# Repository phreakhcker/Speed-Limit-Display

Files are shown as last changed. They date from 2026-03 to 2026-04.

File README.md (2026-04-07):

# Speed Limit Display

A real-time speed limit display built with an ESP32, GPS module, and OLED screen. Shows the current road's speed limit with color-coded overspeed warnings (green/yellow/red).

Uses the TomTom Snap-to-Roads API for accurate road matching — sends your heading and speed so it picks the correct road, even near highway ramps and parallel roads.

## Hardware

| Component | Details |
|---|---|
| Microcontroller | ESP32 Mini (any variant: original, S2, S3, C3) |
| GPS Module | Any NMEA-compatible (NEO-6M, NEO-7M, BN-220, etc.) |
| Display | SSD1351 128x128 SPI OLED |
| Button | One momentary pushbutton |
| Power | USB or 5V supply |

## Wiring

| ESP32 Pin | Connects To |
|---|---|
| GPIO 20 | GPS TX |
| GPIO 21 | GPS RX |
| GPIO 7 | OLED CS |
| GPIO 2 | OLED DC |
| GPIO 3 | OLED RST |
| GPIO 4 | OLED MOSI (SDA) |
| GPIO 6 | OLED SCLK (SCL) |
| GPIO 10 | Button (other leg to GND) |

Pin assignments can be changed in `config.h`.

## Features

- **Snap-to-Roads API** — sends GPS heading + speed for accurate road matching
- **GPS point buffering** — 5-point trajectory for better map matching
- **Speed limit smoothing** — rejects false readings from nearby roads
- **Overspeed alerts** — green (ok), yellow (close to limit), red (over limit) with hysteresis
- **Dual-core HTTP** — API calls on Core 0, GPS/display on Core 1 (no display freezes)
- **Non-blocking WiFi** — GPS keeps working during WiFi reconnects
- **API rate limiting** — exponential backoff on HTTP 429, daily quota tracking
- **Watchdog timer** — auto-reboots if the device freezes
- **One-button menu** — adjust brightness, alert thresholds, API timing, GPS reset
- **Persistent settings** — brightness and thresholds saved across reboots

## Setup

### 1. Install Arduino Libraries

Open Arduino IDE, go to **Sketch > Include Library > Manage Libraries** and install:

- **TinyGPSPlus** (by Mikal Hart)
- **ArduinoJson** (by Benoit Blanchon, version 6.x)
- **Adafruit GFX Library**
- **Adafruit SSD1351 Library**

### 2. Get a TomTom API Key (free)

1. Go to [developer.tomtom.com](https://developer.tomtom.com)
2. Create a free account
3. Go to Dashboard > My Apps > Add New App
4. Copy your API key (free tier = 2,500 requests/day)

### 3. Configure Credentials

1. In the `SpeedLimitDisplay/` folder, copy `config_secrets_example.h` to `config_secrets.h`
2. Edit `config_secrets.h` with your WiFi name, password, and TomTom API key
3. `config_secrets.h` is in `.gitignore` — it will never be uploaded to GitHub

### 4. Upload to ESP32

1. Open `SpeedLimitDisplay/SpeedLimitDisplay.ino` in Arduino IDE
2. Select your ESP32 board in **Tools > Board**
3. Click **Upload**

### 5. Serial Monitor (optional, for debugging)

Open **Tools > Serial Monitor** at 115200 baud. Type:
- **`d`** — full debug status dump
- **`r`** — reboot the device

## Button Controls

| Action | Normal Mode | Menu Mode |
|---|---|---|
| Short press | Cycle brightness | Next menu item |
| Long press (1.2s) | Enter menu | Change selected setting |
| Very long press (2.5s) | — | Exit menu |

## Configuration

All tunable settings (pins, timing, thresholds) are in `config.h`. Secrets (WiFi, API key) are in `config_secrets.h`.

## Custom PCB (v2)

A custom 2-layer PCB designed in KiCad 10.0 with everything on one board:

| Component | Details |
|---|---|
| U1 | ESP32-S3-WROOM-1-N8 (dual core, 8MB flash, WiFi+BLE) |
| U2 | Quectel L70-R GPS module with ceramic patch antenna |
| U3 | LV75530PDBV 3.3V LDO regulator |
| J1 | USB-C connector (power + programming) |
| J2 | 12-pin display header |
| J4 | 9-pin breakout header (spare GPIOs + power for future expansion) |
| SW1 | EC11 rotary encoder with push button (menu navigation) |
| SW3/SW4 | Boot and reset buttons |
| BZ1 | Piezo buzzer (optional) |

Gerber files are in `PCB Design/.../Gerber/` ready to upload to PCBWay or JLCPCB.

See [docs/hardware/PCB_DESIGN.md](docs/hardware/PCB_DESIGN.md) for full design details, ordering instructions, and assembly guide.

## Project Structure

```
Speed-Limit-Display/
├── SpeedLimitDisplay/              # Arduino sketch folder
│   ├── SpeedLimitDisplay.ino       # Main code
│   ├── config.h                    # All tunable settings
│   ├── config_secrets.h            # Your credentials (git-ignored)
│   └── config_secrets_example.h    # Template for credentials
├── PCB Design/                     # KiCad PCB project
│   └── .../Speed-Limit-Display-v2/
│       ├── *.kicad_sch             # Schematic
│       ├── *.kicad_pcb             # PCB layout
│       ├── *.kicad_dru             # Custom DRC rules
│       └── Gerber/                 # Manufacturing files (.zip)
├── docs/
│   ├── hardware/
│   │   ├── PCB_DESIGN.md           # PCB specs, ordering, assembly guide
│   │   └── DRC_FIXES_CHECKLIST.md  # DRC fixes applied
│   └── PRODUCT_PLAN.md             # Product roadmap
├── .gitignore
├── CONTRIBUTING.md                 # How to contribute
├── LICENSE
└── README.md                       # This file
```

## Contributing

See [CONTRIBUTING.md](CONTRIBUTING.md) for how to set up your environment, create branches, and submit changes.

## License

See [LICENSE](LICENSE) for details.

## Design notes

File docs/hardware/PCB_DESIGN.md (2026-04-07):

# Custom PCB Design — Speed Limit Display v2

All-in-one board: ESP32-S3 + GPS + Display + Power + Controls.

Designed in KiCad 10.0 for manufacturing by JLCPCB/PCBWay.

---

## Current Status

**Phase: PCB layout complete, DRC passing (warnings only)**

- Schematic: Complete
- PCB Layout: Complete (2-layer, fully routed)
- DRC: Passing (0 errors, cosmetic warnings only)
- Next: Generate Gerbers and order prototype boards

---

## Design Goals

1. Everything on one board (no breakout modules, no jumper wires)
2. Small enough for a car-mount enclosure
3. USB-C for power and programming
4. Display connector (12-pin header)
5. GPS with on-board antenna (L70-R module with ceramic patch)
6. Rotary encoder + push button for tactile control
7. Boot and reset buttons for firmware flashing
8. Piezo buzzer footprint (optional populate)
9. 2-layer PCB (keeps cost low)

---

## Design Tool

**KiCad 10.0** (migrated from EasyEDA due to missing footprints in EasyEDA library).

### KiCad Project Files

```
PCB Design/
  SCH_Speed-Limit-Display_2026-03-29_v45_2026-04-01-11-26/
    Speed-Limit-Display-v2/
      Speed-Limit-Display-v2.kicad_sch    # Schematic
      Speed-Limit-Display-v2.kicad_pcb    # PCB layout
      Speed-Limit-Display-v2.kicad_pro    # Project settings
      Speed-Limit-Display-v2.kicad_dru    # Custom design rules
      Speed-Limit-Display-v2.csv          # BOM export
```

---

## Component Selection (BOM)

### Core Components

| Ref | Component | Part Number | Package | Qty | Notes |
|-----|---|---|---|-----|---|
| U1 | ESP32-S3-WROOM-1-N8 | ESP32-S3-WROOM-1-N8 | Module (40-pin) | 1 | Dual core, 8MB flash, WiFi+BLE, built-in antenna |
| U2 | GPS Receiver | L70-R (Quectel) | LCC | 1 | NMEA output, built-in ceramic patch antenna |
| U3 | 3.3V LDO Regulator | LV75530PDBV | SOT-23-5 | 1 | 5V USB to 3.3V for ESP32 + GPS |
| U4 | Voltage Level Shifter | — | SOT-23-6 | 1 | Signal level translation |

### Display

| Ref | Component | Notes |
|-----|---|---|
| J2 | 12-pin display connector | Conn_01x12_Pin, 0.5mm pitch header |

### Power & Protection

| Ref | Component | Value | Package | Qty | Notes |
|-----|---|---|---|-----|---|
| J1 | USB-C Connector | USB 2.0 | SMD 16-pin | 1 | Power + data (ESP32-S3 native USB) |
| F1 | Resettable fuse | 500mA PTC | 0805 | 1 | USB overcurrent protection |
| D1 | LED indicator | — | SMD | 1 | Power/status |
| D2 | TVS diode | D_TVS500mA | SMD | 1 | USB ESD protection |
| C1-C6 | Decoupling capacitors | 100nF - 10uF | 0805 | 6 | Power filtering |

### User Interface

| Ref | Component | Part Number | Package | Qty | Notes |
|-----|---|---|---|-----|---|
| SW1 | Rotary encoder with push | EC11 compatible | Through-hole | 1 | Rotate = navigate, push = select |
| SW3 | Boot button | Tactile push | SMD | 1 | Hold during reset for firmware flash mode |
| SW4 | Reset button | Tactile push | SMD | 1 | Reset/EN control |
| BZ1 | Piezo buzzer | 5V passive | Through-hole | 1 | Optional — don't populate for silent version |

### Passive Components

| Ref | Component | Value | Package | Qty | Notes |
|-----|---|---|---|-----|---|
| R1 | LED resistor | 1K | 0805 | 1 | For D1 |
| R2, R3 | USB CC resistors | 5.1K | 0805 | 2 | Tell USB host we want 5V |
| R4 | Pull-up resistor | 10K | 0805 | 1 | Boot mode pull-up |
| R5, R6 | I2C/signal resistors | 5.1K | 0805 | 2 | Signal conditioning |
| R7, R8 | USB data resistors | 22R | 0805 | 2 | USB D+/D- series termination |

### Connectors

| Ref | Component | Notes |
|-----|---|---|
| J1 | USB-C receptacle | Power input + USB data |
| J2 | 12-pin header | Display connector |
| J3 | Coaxial connector | External GPS antenna (optional) |

---

## Schematic — Block Diagram

```
                                    +---------------------+
   USB-C --> 5V --> LV75530 --> 3V3 |                     |
      |            (LDO)           |  ESP32-S3-WROOM-1   |
      |                            |                     |
      |   D+/D- -------------------|  GPIO 19/20 (USB)   |
      |                            |                     |
      |                            |  SPI Bus --> Display |
      |                            |  (via J2 header)    |
      |                            |                     |
      |                            |  UART --> GPS (U2)  |
      |                            |  GPIO 17 (RX)       |
      |                            |  GPIO 18 (TX)       |
      |                            |                     |
      |                            |  Rotary Encoder:    |
      |                            |  GPIO 5  (A)        |
      |                            |  GPIO 6  (B)        |
      |                            |  GPIO 7  (SW)       |
      |                            |                     |
      |                            |  Buzzer: GPIO 14    |
      |                            |  EN <-- Reset Btn   |
      |                            |  IO0 <-- Boot Btn   |
      |                            +---------------------+
```

---

## PCB Layout Details

### Board Specifications

| Parameter | Value |
|---|---|
| Layers | 2 (F.Cu + B.Cu) |
| Copper weight | 1 oz |
| Board thickness | 1.6mm |
| Surface finish | HASL (lead-free) or ENIG |
| Solder mask | Default (green or black) |
| Silkscreen | White |

### Design Rules Applied

| Rule | Value | Notes |
|---|---|---|
| Signal trace width | 0.25mm | Default netclass |
| Power trace width | 0.3mm | Power netclass (+3V3, +5V, GND) |
| Clearance | 0.15mm | Both Default and Power netclasses |
| Min drill size | 0.2mm | For ESP32 thermal vias |
| Via size | 0.5mm pad / 0.2mm drill | Standard stitching and signal vias |
| Copper to edge clearance | 0.0mm | Relaxed for edge-mounted connectors (J1, BZ1) |

### Custom DRC Rules (in .kicad_dru)

```
(rule "USB-C connector"
  (condition "A.Reference == 'J1' && B.Reference == 'J1'")
  (constraint clearance (min 0.1mm))
)

(rule "Edge components"
  (condition "A.Type == 'pad' && (A.Reference == 'J1' || A.Reference == 'BZ1' || A.Reference == 'U2')")
  (constraint edge_clearance (min 0mm))
)
```

### Copper Zones

- **F.Cu GND pour** — solid fill, covers entire board, GND net
- **B.Cu GND pour** — solid fill, covers entire board, GND net
- **Pad connections** — Solid (not thermal relief) for better connectivity
- **Stitching vias** — placed throughout to connect F.Cu and B.Cu ground planes
- **Antenna keep-out zone** — no copper under ESP32 antenna area

### Net Classes

| Netclass | Track Width | Via Size | Clearance | Nets |
|---|---|---|---|---|
| Default | 0.25mm | 0.5mm | 0.15mm | All signal nets |
| Power | 0.3mm | 0.5mm | 0.15mm | +3V3, +5V, GND |

---

## DRC Status

### Final DRC Results (2026-04-05)

- **Errors: 0**
- **Warnings: 10** (all cosmetic silkscreen issues)
- **Unconnected pads: 0**

### Remaining Warnings (safe to ignore)

| Warning | Count | Why It's OK |
|---|---|---|
| Silkscreen clipped by board edge | 4 | J1 and SW3 labels at board edge — fab clips automatically |
| Silkscreen overlap | 2 | R7/R8 and C3/J3 reference labels overlap — cosmetic only |
| Silkscreen over copper | 3 | R7 and C2 labels over pads — fab clips automatically |
| Duplicate via | 1 | Two vias at same location — harmless, can delete one |

### Ignored DRC Checks

| Check | Reason |
|---|---|
| Board edge clearance | USB-C (J1) and buzzer (BZ1) intentionally at board edge |
| Thermal relief incomplete | B.Cu zone uses solid connections; some pads only have 1 spoke which is sufficient |
| Footprint courtyard | Not all footprints have courtyard defined — does not affect manufacturing |

---

## Manufacturing — Generating Gerbers

### From KiCad:

1. **File > Fabrication Outputs > Gerbers (.gbr)**
2. Select output directory
3. Check all layers: F.Cu, B.Cu, F.Mask, B.Mask, F.Silkscreen, B.Silkscreen, Edge.Cuts
4. Click "Generate"
5. **File > Fabrication Outputs > Drill Files (.drl)**
6. Generate drill files in the same directory

### Files to Upload

| File | Layer |
|---|---|
| F.Cu.gbr | Front copper |
| B.Cu.gbr | Back copper |
| F.Mask.gbr | Front solder mask |
| B.Mask.gbr | Back solder mask |
| F.Silkscreen.gbr | Front silkscreen |
| B.Silkscreen.gbr | Back silkscreen |
| Edge.Cuts.gbr | Board outline |
| *.drl | Drill files |

### Recommended Fab Houses

| Fab House | Notes |
|---|---|
| **JLCPCB** | Cheapest for prototypes, fast turnaround, supports 0.2mm min drill |
| **PCBWay** | Good quality, assembly service available |

### Order Specs

- Layers: 2
- Quantity: 5 (prototype)
- Thickness: 1.6mm
- Surface finish: HASL lead-free
- Solder mask color: Your choice (black looks professional)
- Silkscreen: White
- Min hole size: 0.2mm
- Min trace/space: 0.15mm / 0.15mm

---

## Assembly Notes

### Components Requiring Hand Soldering
- ESP32-S3-WROOM-1 (large module, requires careful alignment)
- USB-C connector (fine pitch pads)
- All SMD passives (0805 size — manageable with soldering iron)

### Assembly Order (recommended)
1. LDO regulator (U3) and decoupling caps (C1-C6)
2. USB-C connector (J1) and protection components (F1, D2)
3. USB resistors (R2, R3, R7, R8)
4. ESP32-S3 module (U1) — solder pads first, then reflow ground pad
5. GPS module (U2) and antenna connector (J3)
6. Signal resistors (R1, R4-R6)
7. Level shifter (U4) and LED (D1)
8. Through-hole components last: rotary encoder (SW1), buzzer (BZ1)
9. Push buttons (SW3, SW4)
10. Display connector (J2)

### Testing After Assembly
1. Check for shorts between +5V, +3V3, and GND with multimeter
2. Apply USB power — verify 3.3V on LDO output
3. Connect via USB — ESP32 should appear as USB device
4. Flash firmware and verify GPS, display, encoder, buttons, buzzer

---

## Future-Proofing: Breakout Header (J4)

A 9-pin breakout header (J4) was added to expose unused GPIO pins and power rails
for future expansion without requiring a board respin.

| J4 Pin | Net | Purpose |
|---|-----|---|
| 1 | +3V3 | 3.3V power output |
| 2 | +5V | 5V power (direct from USB) |
| 3 | GND | Ground |
| 4 | IO35 | General purpose GPIO (SPI, buttons) |
| 5 | IO36 | General purpose GPIO (SPI, buttons) |
| 6 | IO45 | General purpose GPIO (I2C for sensors) |
| 7 | IO46 | General purpose GPIO (I2C for sensors) |
| 8 | TXD0 | Debug UART TX (serial monitor without USB) |
| 9 | RXD0 | Debug UART RX (serial monitor without USB) |

**Potential uses:**
- Ambient light sensor (BH1750 or VEML7700 via I2C on IO45/IO46) for auto-brightness
- Accelerometer for motion detection
- External serial debug without occupying USB port
- Additional buttons or sensors
- Powering small external accessories (3.3V or 5V)

---

## Generating Gerber Files

### Step-by-step in KiCad:

#### 1. Generate Gerber files

1. Open the PCB editor (Speed-Limit-Display-v2.kicad_pcb)
2. Go to **File > Fabrication Outputs > Gerbers (.gbr)**
3. Set the **Output directory** to a folder like `Gerbers/`
4. Under **Layers**, check all of these:
   - F.Cu (front copper)
   - B.Cu (back copper)
   - F.Paste (front paste — for stencil)
   - B.Paste (back paste)
   - F.Silkscreen (front silkscreen)
   - B.Silkscreen (back silkscreen)
   - F.Mask (front solder mask)
   - B.Mask (back solder mask)
   - Edge.Cuts (board outline)
5. Under **General Options**:
   - Check "Use Protel filename extensions" (for compatibility)
   - Check "Subtract soldermask from silkscreen"
6. Click **Plot** to generate

#### 2. Generate Drill files

1. In the same Gerber dialog, click **Generate Drill Files...**
2. Set format to **Excellon**
3. Check "PTH and NPTH in single file" (most fabs prefer this)
4. Drill units: **Millimeters**
5. Click **Generate Drill File**

#### 3. Verify Gerbers

1. In KiCad, go to **File > Fabrication Outputs > Gerber Viewer** (or use the standalone GerbView)
2. Open all generated files and visually check:
   - All traces visible on copper layers
   - Board outline is a closed shape
   - Solder mask openings align with pads
   - Silkscreen is readable and not overlapping pads
   - Drill holes are present and correctly sized

### Output files (with Protel extensions)

| File | Description |
|---|---|
| .GTL | Front copper (F.Cu) |
| .GBL | Back copper (B.Cu) |
| .GTS | Front solder mask (F.Mask) |
| .GBS | Back solder mask (B.Mask) |
| .GTO | Front silkscreen (F.Silkscreen) |
| .GBO | Back silkscreen (B.Silkscreen) |
| .GTP | Front paste (F.Paste) |
| .GBP | Back paste (B.Paste) |
| .GKO or .GM1 | Board outline (Edge.Cuts) |
| .DRL or .XLN | Drill file |

---

## Ordering from PCBWay

### Step-by-step:

1. **Zip all Gerber + drill files** into a single .zip file
2. Go to [pcbway.com](https://www.pcbway.com) and click **Quote Now**
3. Click **Quick-order PCB** > **Add Gerber File** and upload your .zip
4. PCBWay will auto-detect board dimensions and layer count
5. Set the following specs:

| Setting | Value |
|---|---|
| Layers | 2 |
| Dimensions | (auto-detected from Gerbers) |
| Quantity | 5 (minimum for prototype) |
| Thickness | 1.6mm |
| Surface finish | HASL (lead-free) — cheapest option |
| Solder mask color | Black (or your preference) |
| Silkscreen color | White |
| Min hole size | 0.2mm |
| Min track/spacing | 6/6 mil (0.15mm/0.15mm) |
| Copper weight | 1 oz |
| Gold fingers | No |
| Castellated holes | No |

6. Click **Save to Cart** and proceed to checkout
7. Typical turnaround: 3-5 business days manufacturing + shipping

### Ordering from JLCPCB (alternative)

1. Go to [jlcpcb.com](https://www.jlcpcb.com) and click **Order Now**
2. Upload the same .zip file
3. JLCPCB auto-detects specs — review and adjust:
   - Same settings as PCBWay table above
   - JLCPCB offers 5 PCBs for ~$2 + shipping
   - Select shipping method (DHL ~$15-20 for 5-7 day delivery)
4. Add to cart and checkout

### Assembly Service (PCBA) — Optional

Both PCBWay and JLCPCB offer assembly where they solder components for you.
To use this service, you also need:

1. **BOM file** (Bill of Materials) — exported from KiCad:
   - Go to schematic editor > **Tools > Edit Symbol Fields** > **Export to CSV**
   - Or use the existing `Speed-Limit-Display-v2.csv`
   - Format: Reference, Value, Footprint, LCSC Part Number

2. **CPL file** (Component Placement List) — exported from KiCad:
   - Go to PCB editor > **File > Fabrication Outputs > Component Placement (.pos)**
   - This tells the pick-and-place machine where to put each component

3. Upload BOM + CPL along with Gerbers when ordering
4. The fab house will show you which parts they have in stock
5. For parts not in stock, you may need to supply them yourself

**Note:** Assembly adds ~$30-50 for small quantities. For 5 prototype boards,
hand soldering is usually more cost-effective. Use assembly service for
larger batches (20+).

---

## Ordering Components

### Recommended Suppliers

| Supplier | Best for | Notes |
|---|---|---|
| **LCSC** | All SMD parts, ESP32 modules | Cheapest, ships from China, pairs with JLCPCB |
| **Digikey** | Everything | Fast US shipping, best search/filtering |
| **Mouser** | Everything | Similar to Digikey, good stock |
| **AliExpress** | GPS modules, displays, encoders | Cheapest for breakout modules, slow shipping |

### Key Parts to Source

| Component | Where to Buy | Search Term |
|---|---|---|
| ESP32-S3-WROOM-1-N8 | LCSC or Digikey | ESP32-S3-WROOM-1-N8 |
| Quectel L70-R GPS | LCSC or AliExpress | L70-R or L70-RE |
| USB-C connector | LCSC | USB-C 16P SMD |
| EC11 rotary encoder | AliExpress or LCSC | EC11 encoder with switch |
| 0805 resistors/caps | LCSC | Order assortment kit |
| Piezo buzzer | LCSC or AliExpress | 12mm passive buzzer |

---

## Design History

| Date | Change |
|---|---|
| 2026-03-29 | Initial schematic created in EasyEDA |
| 2026-04-01 | Migrated to KiCad 10.0 (EasyEDA missing footprints) |
| 2026-04-01 | Schematic rebuild in KiCad with all components |
| 2026-04-05 | PCB layout complete — all traces routed |
| 2026-04-05 | GND copper pour added (F.Cu + B.Cu) |
| 2026-04-05 | DRC passing with 0 errors |
| 2026-04-06 | Added J4 breakout header (9-pin) for future expansion |
| 2026-04-06 | Final DRC: 0 errors, 2 cosmetic warnings only |

---

## Next Steps

1. **Generate Gerbers** from KiCad (see instructions above)
2. **Verify Gerbers** in GerbView or online viewer
3. **Upload to PCBWay or JLCPCB** and order prototype boards
4. **Order components** from LCSC or Digikey
5. **Assemble prototype** board (hand solder or PCBA service)
6. **Test and validate** all circuits
7. **Update firmware** config.h pin assignments to match PCB
8. **Iterate** if needed based on testing results

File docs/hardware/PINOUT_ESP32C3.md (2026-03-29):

# Pinout Map — Current Prototype

## Components

| Component | Model | Interface | Notes |
|---|---|---|---|
| Microcontroller | ESP32-C3 Mini | — | Single core, WiFi, BLE, RISC-V |
| GPS Module | GT-U7 (Goouuu Tech) | UART | u-blox NEO-6M compatible. Uses UBX protocol (NOT PMTK) |
| Display | SSD1351 128x128 OLED | SPI | 1.5" RGB OLED, 65K colors |
| Button | Momentary pushbutton | GPIO (INPUT_PULLUP) | Between pin and GND |

---

## ESP32-C3 Mini Pinout

```
                    ESP32-C3 Mini
                  ┌───────────────┐
                  │    USB-C      │
                  │  ┌─────────┐  │
            3V3 ──┤  │         │  ├── 5V
            GND ──┤  │ ESP32-C3│  ├── GND
          GPIO0 ──┤  │         │  ├── GPIO10  ← BUTTON
          GPIO1 ──┤  │         │  ├── GPIO9
      SDA GPIO2 ──┤  │         │  ├── GPIO8
          GPIO3 ──┤  │         │  ├── GPIO21  → GPS RX (ESP TX)
  SPI MOSI GPIO4 ──┤  │         │  ├── GPIO20  ← GPS TX (ESP RX)
          GPIO5 ──┤  │         │  ├── GPIO7   → OLED CS
  SPI SCLK GPIO6 ──┤  └─────────┘  ├── GPIO1
                  └───────────────┘

  Note: Actual pin layout may vary by manufacturer.
  Always check YOUR specific board's silkscreen labels.
```

---

## Wiring Connections

### Display (SSD1351 128x128 SPI OLED)

```
  ESP32-C3          SSD1351 OLED
  ────────          ────────────
  GPIO 4  ────────→ SDA (MOSI)     Data line
  GPIO 6  ────────→ SCL (SCLK)     Clock line
  GPIO 7  ────────→ CS              Chip Select
  GPIO 2  ────────→ DC              Data/Command
  GPIO 3  ────────→ RST             Reset
  3V3     ────────→ VCC             Power (3.3V)
  GND     ────────→ GND             Ground
```

### GPS Module (GT-U7)

```
  ESP32-C3          GT-U7 GPS
  ────────          ─────────
  GPIO 20 ←──────── TX              GPS sends data TO ESP32
  GPIO 21 ────────→ RX              ESP32 sends commands TO GPS
  3V3     ────────→ VCC             Power (3.3V — check if module needs 5V)
  GND     ────────→ GND             Ground

  ⚠️  IMPORTANT: The GT-U7 may need 5V power (check your module).
     If so, connect VCC to 5V, but the TX/RX data lines are still
     3.3V logic and safe to connect directly to the ESP32.
```

### Button

```
  ESP32-C3          Button
  ────────          ──────
  GPIO 10 ────────→ Pin 1
  GND     ────────→ Pin 2

  No external resistor needed — we use INPUT_PULLUP
  (the ESP32 has a built-in pull-up resistor on the pin).
```

---

## Complete Wiring Diagram

```
                           ┌──────────────┐
                           │  SSD1351     │
                           │  128x128     │
                           │  OLED        │
                           │              │
                    ┌──────┤ SDA     VCC ├─── 3V3
                    │ ┌────┤ SCL     GND ├─── GND
                    │ │ ┌──┤ CS          │
                    │ │ │┌─┤ DC          │
                    │ │ ││┌┤ RST         │
                    │ │ │││└──────────────┘
                    │ │ │││
  ┌─────────────────┼─┼─┼┼┼────────────────┐
  │ ESP32-C3 Mini   │ │ │││                │
  │                 │ │ │││                │
  │  GPIO 4 ───────┘ │ │││  GPIO 20 ◄──── │ ──── GPS TX
  │  GPIO 6 ──────────┘ │││  GPIO 21 ────► │ ──── GPS RX
  │  GPIO 7 ─────────────┘││                │
  │  GPIO 2 ──────────────┘│                │
  │  GPIO 3 ───────────────┘                │
  │                                         │
  │  GPIO 10 ─────────────── BUTTON ── GND  │
  │                                         │
  │  3V3 ──────────────────── GPS VCC       │
  │  GND ──────────────────── GPS GND       │
  │  5V (USB) ── Power In                   │
  └─────────────────────────────────────────┘
```

---

## Pin Summary Table

| ESP32-C3 Pin | Connected To | Direction | Function |
|---|---|---|---|
| GPIO 2 | OLED DC | Output | Data/Command select |
| GPIO 3 | OLED RST | Output | Display reset |
| GPIO 4 | OLED SDA (MOSI) | Output | SPI data to display |
| GPIO 6 | OLED SCL (SCLK) | Output | SPI clock |
| GPIO 7 | OLED CS | Output | SPI chip select |
| GPIO 10 | Button | Input (pullup) | Menu/brightness button |
| GPIO 20 | GPS TX | Input | Receive GPS NMEA data |
| GPIO 21 | GPS RX | Output | Send UBX commands to GPS |
| 3V3 | OLED VCC, GPS VCC | Power | 3.3V supply |
| GND | OLED GND, GPS GND, Button | Power | Common ground |
| 5V (USB) | — | Power | USB power input |

---

## GT-U7 GPS Module Pinout

```
  GT-U7 Module
  ┌─────────────────────┐
  │  ┌───┐              │
  │  │GPS│  Ceramic      │
  │  │Ant│  Antenna      │
  │  └───┘              │
  │                     │
  │  VCC  TX  RX  GND   │
  └──┬───┬───┬───┬──────┘
     │   │   │   │
     5V  │   │   GND
         │   │
    ESP  │   ESP
    RX   │   TX
   (20)  │  (21)
         │
   (data flows FROM GPS TO ESP32)
```

### GT-U7 Specs
- **Chip:** u-blox NEO-6M compatible
- **Default baud rate:** 9600
- **Protocol:** NMEA 0183 + UBX binary
- **Update rate:** 1Hz default, up to 5Hz (10Hz on some clones — may not be stable)
- **Antenna:** Built-in ceramic patch antenna
- **Cold start:** ~27 seconds
- **Hot start:** ~1 second
- **Power:** 3.3V-5V (check your specific module)

### ⚠️ Important Note About GPS Commands

The GT-U7 uses **u-blox UBX protocol**, NOT MediaTek PMTK commands.
If you see "PMTK" in the code, those commands won't work on your module.
The code must use UBX binary commands to configure:
- Update rate (default 1Hz → target 5Hz)
- Navigation mode (pedestrian → automotive)
- Baud rate (9600 → 38400)
- Message filtering (reduce to RMC+GGA only)

---

## ESP32-C3 Limitations for This Project

| Feature | ESP32-C3 | ESP32-S3 (product target) |
|---|---|---|
| CPU Cores | 1 (RISC-V) | 2 (Xtensa) |
| Clock Speed | 160 MHz | 240 MHz |
| RAM | 400 KB | 512 KB + optional 8MB PSRAM |
| WiFi | Yes | Yes |
| Bluetooth | BLE only | BLE + Classic |
| USB | CDC (serial only) | OTG (can act as USB device) |
| SPI interfaces | 1 usable | 2 usable |
| Background HTTP | ❌ Falls back to inline | ✅ Runs on Core 0 |
| Touch display | Works but tight on RAM | ✅ Plenty of resources |

**Recommendation:** The ESP32-C3 is fine for prototyping, but the product PCB should use an **ESP32-S3-WROOM-1** module for dual-core performance and better display handling.

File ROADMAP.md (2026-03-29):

# Speed Limit Display — Product Roadmap

Full plan from working prototype to selling a finished product.

---

## Phase 1 — Code Foundation (DONE)

Everything already completed in Rev 4.1.

- [x] Snap-to-Roads API with heading + speed
- [x] GPS point buffering (5-point trajectory)
- [x] Speed limit smoothing (outlier rejection)
- [x] 38400 baud GPS (10Hz support)
- [x] Non-blocking WiFi
- [x] Low-speed dead zone
- [x] Watchdog timer
- [x] Credential separation (config_secrets.h)
- [x] Configurable settings (config.h)

## Phase 2 — Reliability (DONE)

- [x] Dual-core background HTTP (Core 0)
- [x] API rate limit handling (HTTP 429 + exponential backoff)
- [x] Daily API quota tracking with warnings
- [x] WiFi exponential backoff on reconnect
- [x] WiFi disconnect/reconnect logging

## Phase 3 — Field Testing & Bug Fixes

Real-world driving to validate all the Phase 1-2 improvements.

- [ ] 3.1 Flash Rev 4.1 to ESP32 and bench test (power on, GPS lock, WiFi connect)
- [ ] 3.2 Drive test: suburban roads (25-45 mph zones, frequent limit changes)
- [ ] 3.3 Drive test: highway (65-75 mph, parallel frontage roads)
- [ ] 3.4 Drive test: rural (spotty WiFi/GPS, long stretches between limit signs)
- [ ] 3.5 Review serial debug output — verify Snap-to-Roads vs Reverse Geocode usage
- [ ] 3.6 Log speed limit accuracy: note what the display shows vs actual posted signs
- [ ] 3.7 Fix any bugs found during testing
- [ ] 3.8 Tune config.h values based on real-world results (API interval, move threshold, smoothing)

## Phase 4 — Display & UI Improvements

Better screen, more information, polished user experience.

- [ ] 4.1 Evaluate display upgrade: 2.0" IPS TFT (ST7789, 240x320) — better sunlight readability
- [ ] 4.2 Show BOTH current speed AND speed limit on screen (speed on top, limit below)
- [ ] 4.3 Add road name display (TomTom returns the road name in the API response)
- [ ] 4.4 Speed limit change animation (brief flash/highlight when the limit changes)
- [ ] 4.5 Add "approaching limit" indicator (speed bar or gauge that fills up)
- [ ] 4.6 Night mode: auto-dim based on ambient light sensor (optional LDR add-on)
- [ ] 4.7 Startup animation / splash screen with version number
- [ ] 4.8 Low battery / power loss indicator (if running on battery)

## Phase 5 — Input & Controls

Replace single button with something more intuitive.

- [ ] 5.1 Add rotary encoder with push button (rotate = scroll, push = select)
- [ ] 5.2 Redesign menu system for rotary encoder navigation
- [ ] 5.3 Add "quick settings" — single rotate to adjust brightness without entering menu
- [ ] 5.4 (Optional) Evaluate capacitive touch display for future "Pro" version

## Phase 6 — Audio Alerts

Optional sound feedback for overspeed.

- [ ] 6.1 Add piezo buzzer for overspeed beep
- [ ] 6.2 Make alert configurable: off / single beep / continuous
- [ ] 6.3 Add alert volume levels (PWM duty cycle)
- [ ] 6.4 Save audio preferences to NVS
- [ ] 6.5 (Optional) Evaluate small speaker for voice alerts ("Speed limit: 65")

## Phase 7 — WiFi Setup Portal

First-boot experience so users don't need to edit code.

- [ ] 7.1 On first boot (no saved WiFi), create a WiFi hotspot ("SpeedLimit-Setup")
- [ ] 7.2 Serve a web page where user enters WiFi name, password, and TomTom API key
- [ ] 7.3 Save credentials to NVS and reboot into normal mode
- [ ] 7.4 Add "Factory Reset" option in menu (clears saved WiFi/API key, returns to setup mode)
- [ ] 7.5 Add menu option to re-enter WiFi setup without full reset

## Phase 8 — Multi-WiFi & Phone Hotspot

Use the device anywhere, not just near home WiFi.

- [ ] 8.1 Store up to 5 WiFi networks in NVS
- [ ] 8.2 Auto-scan and connect to the strongest known network
- [ ] 8.3 Add "Add WiFi" option to the setup portal
- [ ] 8.4 Document how to use phone hotspot as the WiFi source (primary use case for driving)

## Phase 9 — OTA Firmware Updates

Update the device over WiFi without plugging in USB.

- [ ] 9.1 Add ArduinoOTA support
- [ ] 9.2 Add menu option: "Check for Updates"
- [ ] 9.3 Host firmware binary on GitHub Releases
- [ ] 9.4 Device downloads and flashes new firmware over WiFi
- [ ] 9.5 Add version check (don't re-flash if already current)

## Phase 10 — Hardware Design (Custom PCB)

Move from breadboard to a real board. **This is the PCBWay phase.**

- [ ] 10.1 Choose final ESP32 variant for product (recommend: ESP32-S3)
- [ ] 10.2 Choose final display (recommend: 2.0" IPS TFT ST7789)
- [ ] 10.3 Choose final GPS module (recommend: BN-220 or BN-880 for antenna quality)
- [ ] 10.4 Design schematic in KiCad or EasyEDA
    - ESP32-S3 module (WROOM or similar)
    - GPS module footprint + antenna keep-out zone
    - Display connector (FPC or pin header)
    - USB-C for power + programming
    - Rotary encoder footprint
    - Buzzer footprint (optional, populate or not)
    - Power regulation (5V USB → 3.3V LDO)
    - Status LED
    - Reset button
    - Boot button (for initial programming)
- [ ] 10.5 PCB layout — 2-layer board, keep GPS antenna area clear of copper
- [ ] 10.6 Generate Gerber files
- [ ] 10.7 Order prototype PCBs from PCBWay (5-10 boards)
- [ ] 10.8 Order components (BOM — Bill of Materials)
- [ ] 10.9 Solder and assemble first prototype board
- [ ] 10.10 Test prototype board — verify all connections, flash firmware
- [ ] 10.11 Rev 2 PCB if changes needed

## Phase 11 — Enclosure Design

A case that looks like a product, not a science project.

- [ ] 11.1 Design 3D-printed enclosure (Fusion 360 or similar)
    - Display window cutout
    - Rotary encoder knob hole
    - USB-C port access
    - GPS antenna area (keep plastic thin or add ceramic antenna)
    - Mounting options: suction cup mount, vent clip, dash pad
- [ ] 11.2 Print prototype enclosure on FDM printer
- [ ] 11.3 Test fit — PCB, display, encoder, GPS
- [ ] 11.4 Iterate on design (usually takes 2-3 revisions)
- [ ] 11.5 Final version in black or dark gray filament
- [ ] 11.6 (Future) Evaluate injection molding if volume justifies it

## Phase 12 — Sponsor Video (PCBWay)

The video you're planning with PCBWay.

- [ ] 12.1 Finish filming A-roll (you using the device, driving, reactions)
- [ ] 12.2 Film B-roll (soldering, assembly, PCB close-ups, 3D printing)
- [ ] 12.3 Film PCBWay unboxing (receiving the boards)
- [ ] 12.4 Screen capture: code walkthrough, serial monitor output
- [ ] 12.5 Edit video: intro → problem → solution → build → demo → PCBWay shoutout
- [ ] 12.6 Add PCBWay affiliate link and repo link in video description
- [ ] 12.7 Upload to YouTube
- [ ] 12.8 Share with PCBWay contact for approval

## Phase 13 — Product Listing Prep

Everything needed before you can sell units.

- [ ] 13.1 Calculate BOM cost per unit (ESP32 + GPS + display + PCB + case + cables)
- [ ] 13.2 Set retail price (typical hardware markup: 3-4x BOM cost)
- [ ] 13.3 Write product description and feature list
- [ ] 13.4 Take professional product photos (white background, lifestyle/car shots)
- [ ] 13.5 Create a simple user manual / quick start guide (1-page PDF)
- [ ] 13.6 Decide on packaging (small box, foam insert, USB cable included?)
- [ ] 13.7 Get TomTom API key instructions ready for customers (or pre-provision keys)
- [ ] 13.8 Decide: do customers need their own API key, or do you provide one?
    - Own key = free for you, slight friction for customer
    - Shared key = smoother UX, but you pay for API overage at scale
    - Recommend: start with customer's own key, evaluate shared key later

## Phase 14 — Online Store

Where to sell it.

### Option A: Etsy Store
- [ ] 14.1 Create Etsy seller account (if you don't have one)
- [ ] 14.2 Create product listing with photos, description, pricing
- [ ] 14.3 Set up shipping profiles (weight, dimensions, methods)
- [ ] 14.4 Etsy fees: 6.5% transaction fee + $0.20 listing fee + payment processing
- [ ] 14.5 Launch listing

### Option B: Leemerie3D Website
- [ ] 14.6 Create product page on leemerie3d
- [ ] 14.7 Set up payment processing (Stripe, PayPal, or Shopify)
- [ ] 14.8 Set up shipping workflow
- [ ] 14.9 Launch product page

### Option C: Both (Recommended)
- [ ] 14.10 List on Etsy for discoverability (people search Etsy for gadgets)
- [ ] 14.11 List on your own site for higher margins (no Etsy fees)
- [ ] 14.12 Link between them (Etsy listing → your site for support/docs)

## Phase 15 — Post-Launch

After you start selling.

- [ ] 15.1 Set up a simple support system (email or Discord server)
- [ ] 15.2 Create a FAQ page on your website or GitHub wiki
- [ ] 15.3 Collect customer feedback
- [ ] 15.4 Plan v2 features based on feedback:
    - Bluetooth phone app for configuration?
    - Speed camera / red light camera warnings?
    - Trip logging / speed history?
    - Integration with OBD-II for actual vehicle speed (more accurate than GPS)?
    - Heads-up display (HUD) mode — reflect off windshield?
- [ ] 15.5 Consider FCC/regulatory requirements if selling in quantity
    - Unintentional radiator (Part 15) — most ESP32 modules are pre-certified
    - If using a pre-certified ESP32 module, you likely just need FCC ID on the label
    - Consult a compliance advisor if selling more than ~100 units

---

## Cost Estimate (Per Unit, Approximate)

| Component | Estimated Cost |
|---|---|
| ESP32-S3 WROOM module | $3.00 |
| GPS module (BN-220) | $8.00 |
| 2.0" IPS TFT display | $5.00 |
| Custom PCB (at 100 qty) | $1.50 |
| Rotary encoder | $0.75 |
| USB-C connector + LDO + passives | $1.50 |
| 3D printed case | $2.00 |
| USB-C cable (included) | $1.50 |
| Packaging | $1.00 |
| **Total BOM** | **~$24.25** |

At 3x markup: **~$75 retail price**
At 4x markup: **~$97 retail price**

A $79.99 or $89.99 price point feels right for a niche automotive gadget.

---

## Timeline (Rough Estimate)

| Phase | When |
|---|---|
| Phases 1-2 | Done |
| Phase 3 (testing) | This week |
| Phases 4-6 (features) | 2-4 weeks |
| Phases 7-9 (WiFi setup, OTA) | 2-3 weeks |
| Phase 10 (PCB design) | 2-4 weeks (depends on PCBWay turnaround) |
| Phase 11 (enclosure) | 1-2 weeks (parallel with PCB) |
| Phase 12 (video) | 1 week |
| Phases 13-14 (listing) | 1 week |

**Total: roughly 2-3 months from now to first sale**, depending on how much time you put in per week.

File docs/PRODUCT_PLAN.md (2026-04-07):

# Speed Limit Display — Full Product Plan

From prototype to product listing. Check off each task as you complete it.

---

## Phase 3: PCB Design (DONE)

| Done | # | Task | Details |
|---|---|---|---|
| [x] | 3.1 | Fix DRC errors in schematic | All schematic errors resolved |
| [x] | 3.2 | Convert schematic to PCB layout | Full layout in KiCad 10.0 |
| [x] | 3.3 | Route PCB traces + ground plane | All traces routed, GND pour on F.Cu + B.Cu, stitching vias |
| [x] | 3.4 | Add breakout header (J4) | 9-pin header: IO35, IO36, IO45, IO46, TXD0, RXD0, +3V3, +5V, GND |
| [x] | 3.5 | Export Gerbers | Gerber + drill files generated, zipped and ready to upload |
| [ ] | 3.6 | Order from PCBWay/JLCPCB | Upload Gerber zip, order 5-10 boards |

---

## Phase 4: Testing & Bug Fixes

| Done | # | Task | Details |
|---|---|---|---|
| [ ] | 4.1 | Road test current code | Suburban, highway, rural. Log serial output. |
| [ ] | 4.2 | Fix bugs from road testing | Tune config values, fix any issues found |

---

## Phase 5: New Features

| Done | # | Task | Details |
|---|---|---|---|
| [ ] | 5.1 | Buzzer overspeed alert | Beep on yellow/red, configurable in menu |
| [ ] | 5.2 | Road name on display | Parse from TomTom API, show in small text |
| [ ] | 5.3 | Speed limit change animation | Brief flash when limit changes |

---

## Phase 6: Product-Ready Software

| Done | # | Task | Details |
|---|---|---|---|
| [ ] | 6.1 | WiFi setup portal | First-boot hotspot + web config page. REQUIRED for selling. |
| [ ] | 6.2 | OTA firmware updates | Update over WiFi, no USB needed |

---

## Phase 7: Hardware Assembly

| Done | # | Task | Details |
|---|---|---|---|
| [ ] | 7.1 | 3D printed enclosure | Design in Fusion 360, print, test fit |
| [ ] | 7.2 | First complete prototype | Solder PCB + flash firmware + assemble in case |

---

## Phase 8: Marketing Content

| Done | # | Task | Details |
|---|---|---|---|
| [ ] | 8.1 | PCBWay sponsor video | Film, edit, upload to YouTube |

---

## Phase 9: Product Prep

| Done | # | Task | Details |
|---|---|---|---|
| [ ] | 9.1 | Calculate BOM cost + set price | Target $79-89 retail at 3-4x markup |
| [ ] | 9.2 | Product photos | White background + car lifestyle shots |
| [ ] | 9.3 | Product description + quick start guide | For Etsy and website listings |
| [ ] | 9.4 | Packaging design | Box, cable, guide, mount |

---

## Phase 10: Store Setup

| Done | # | Task | Details |
|---|---|---|---|
| [ ] | 10.1 | Etsy listing | Create seller account, list product |
| [ ] | 10.2 | WordPress product page | Add to leemerie3d site with WooCommerce |
| [ ] | 10.3 | Customer support system | Email or Discord + FAQ page |

---

## Phase 11: Beta Testing

| Done | # | Task | Details |
|---|---|---|---|
| [ ] | 11.1 | Beta test with 5-10 people | Build units, collect feedback |
| [ ] | 11.2 | Apply feedback + finalize v1.0 | Fix issues, tag release on GitHub |

---

## Phase 12: Launch

| Done | # | Task | Details |
|---|---|---|---|
| [ ] | 12.1 | Launch on Etsy + website | Go live! Share on social media. |
| [ ] | 12.2 | Post-launch + v2 planning | Monitor 30 days, plan next version |

---

## Progress Tracker

| Phase | Tasks | Status |
|---|---|---|
| 1-2 Code Foundation | All | DONE |
| 3 PCB Design | 5/6 | Nearly Done (order boards) |
| 4 Testing | 0/2 | Not Started |
| 5 Features | 0/3 | Not Started |
| 6 Product Software | 0/2 | Not Started |
| 7 Hardware Assembly | 0/2 | Not Started |
| 8 Marketing | 0/1 | Not Started |
| 9 Product Prep | 0/4 | Not Started |
| 10 Store Setup | 0/3 | Not Started |
| 11 Beta Testing | 0/2 | Not Started |
| 12 Launch | 0/2 | Not Started |
| **Total** | **0/25** | |

---

## What Can Happen In Parallel

Some tasks don't depend on each other and can happen at the same time:

- **PCB design** (Phase 3) + **Road testing** (Phase 4) — test code while designing board
- **New features** (Phase 5) + **PCB manufacturing** (waiting for boards) — code while PCBWay makes boards
- **Enclosure design** (Phase 7.1) + **PCB assembly** (Phase 7.2) — design case while boards ship
- **Video filming** (Phase 8) — film throughout the whole process, not just at the end
- **Product photos** (Phase 9.2) + **Store setup** (Phase 10) — set up accounts while waiting for final photos

---

*Print date: ___________*

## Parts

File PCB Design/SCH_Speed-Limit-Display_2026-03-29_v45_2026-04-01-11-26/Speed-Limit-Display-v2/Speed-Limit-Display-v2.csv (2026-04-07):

Reference | Qty | Value | DNP | Exclude from BOM | Exclude from Board | Footprint | Datasheet
BZ1 | 1 | Buzzer
C1,C3,C4,C5 | 4 | C
C2 | 1 | C_Polarized
D1 | 1 | LED
J1 | 1 | USB_C_Receptacle |  |  |  |  | https://www.usb.org/sites/default/files/documents/usb_type-c.zip
J2 | 1 | Conn_01x12_Pin
J3 | 1 | Conn_Coaxial
R1,R2,R3,R4,R5,R6 | 6 | R
SW1,SW2 | 2 | RotaryEncoder_Switch
SW3,SW4 | 2 | SW_Push
U1 | 1 | ESP32-S3-WROOM-1 |  |  |  | RF_Module:ESP32-S3-WROOM-1 | https://www.espressif.com/sites/default/files/documentation/esp32-s3-wroom-1_wroom-1u_datasheet_en.pdf
U2 | 1 | L70-R |  |  |  | RF_GPS:Quectel_L70-R | https://www.quectel.com/product/gps-only-l70-r
U3 | 1 | AMS1117-3.3 |  |  |  | Package_TO_SOT_SMD:SOT-223-3_TabPin2 | http://www.advanced-monolithic.com/pdf/ds1117.pdf

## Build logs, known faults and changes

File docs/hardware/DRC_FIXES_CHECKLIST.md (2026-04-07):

# DRC Fixes Checklist — Speed Limit Display PCB (KiCad)

**Status: COMPLETE** (2026-04-05)

All DRC errors resolved. Board is ready for Gerber generation.

---

## 1. Schematic Fixes (Completed)

| Done | Component | Pin | Fix Applied |
|---|---|-----|---|
| [x] | U3 Display connector | GND pins | Connected to GND |
| [x] | U3 Display connector | VDD pin | Connected to +3V3 |
| [x] | Boot Button (SW3) | Pin 1 | Connected to ESP32 IO0 |
| [x] | Reset Button (SW4) | Pin 1 | Connected to ESP32 EN |
| [x] | ESP32 (U1) | Pin 41 (EP) | Connected to GND |
| [x] | LDO (U3) | VOUT | Connected to +3V3 |
| [x] | Button duplicate pins | SW3, SW4 | Pin 1+2 pairs connected |

---

## 2. PCB Layout Fixes (Completed)

### Design Rule Settings

| Done | Setting | Value | Location |
|---|---|---|---|
| [x] | Min drill size | 0.2mm | Board Setup > Constraints |
| [x] | Copper to edge clearance | 0.0mm | Board Setup > Constraints |
| [x] | Default netclass clearance | 0.15mm | Board Setup > Net Classes |
| [x] | Power netclass clearance | 0.15mm | Board Setup > Net Classes |
| [x] | Default trace width | 0.25mm | Board Setup > Net Classes |
| [x] | Power trace width | 0.3mm | Board Setup > Net Classes |

### Custom DRC Rules

| Done | Rule | Purpose |
|---|---|---|
| [x] | USB-C connector clearance (0.1mm) | J1 pads are 0.85mm pitch — standard 0.2mm clearance too wide |
| [x] | Edge component clearance (0mm) | J1, BZ1, U2 intentionally at board edge |

### Copper Zones

| Done | Zone | Settings |
|---|---|---|
| [x] | F.Cu GND pour | Solid pad connections, covers full board |
| [x] | B.Cu GND pour | Solid pad connections, covers full board |
| [x] | Stitching vias | Placed to connect zone islands across layers |

### Trace Routing

| Done | Connection | Fix |
|---|---|-----|
| [x] | SW4 pad 1 to EN track | Routed trace to connect |
| [x] | SW3 pad 1 to IO0 track | Routed trace to connect |
| [x] | J2 GND pins (1,2,5,6,12) | Connected via traces and zone pour |
| [x] | U4 pad 2 GND | Connected to zone |
| [x] | All GND pads | Connected via copper pour + stitching vias |

### Ignored Violations (Safe)

| Done | Violation | Severity Set To | Reason |
|---|---|---|---|
| [x] | Board edge clearance | Ignore | Edge-mounted components by design |
| [x] | Thermal relief incomplete | Ignore | Solid connections used; sufficient for this design |
| [x] | Footprint courtyard | Ignore | Not all libs define courtyards |

---

## 3. Final DRC Results

| Check | Result |
|---|---|
| [x] | Errors: **0** |
| [x] | Unconnected pads: **0** |
| [x] | Warnings: **10** (cosmetic silkscreen only) |
| [x] | Footprint errors: **0** |

---

## 4. Ready for Manufacturing

| Step | Status |
|---|---|
| [x] | All traces routed |
| [x] | GND copper pour on both layers |
| [x] | DRC passing |
| [ ] | Generate Gerber files |
| [ ] | Generate drill files |
| [ ] | Upload to fab house (JLCPCB/PCBWay) |
| [ ] | Order prototype boards |

---

*Completed: 2026-04-05*

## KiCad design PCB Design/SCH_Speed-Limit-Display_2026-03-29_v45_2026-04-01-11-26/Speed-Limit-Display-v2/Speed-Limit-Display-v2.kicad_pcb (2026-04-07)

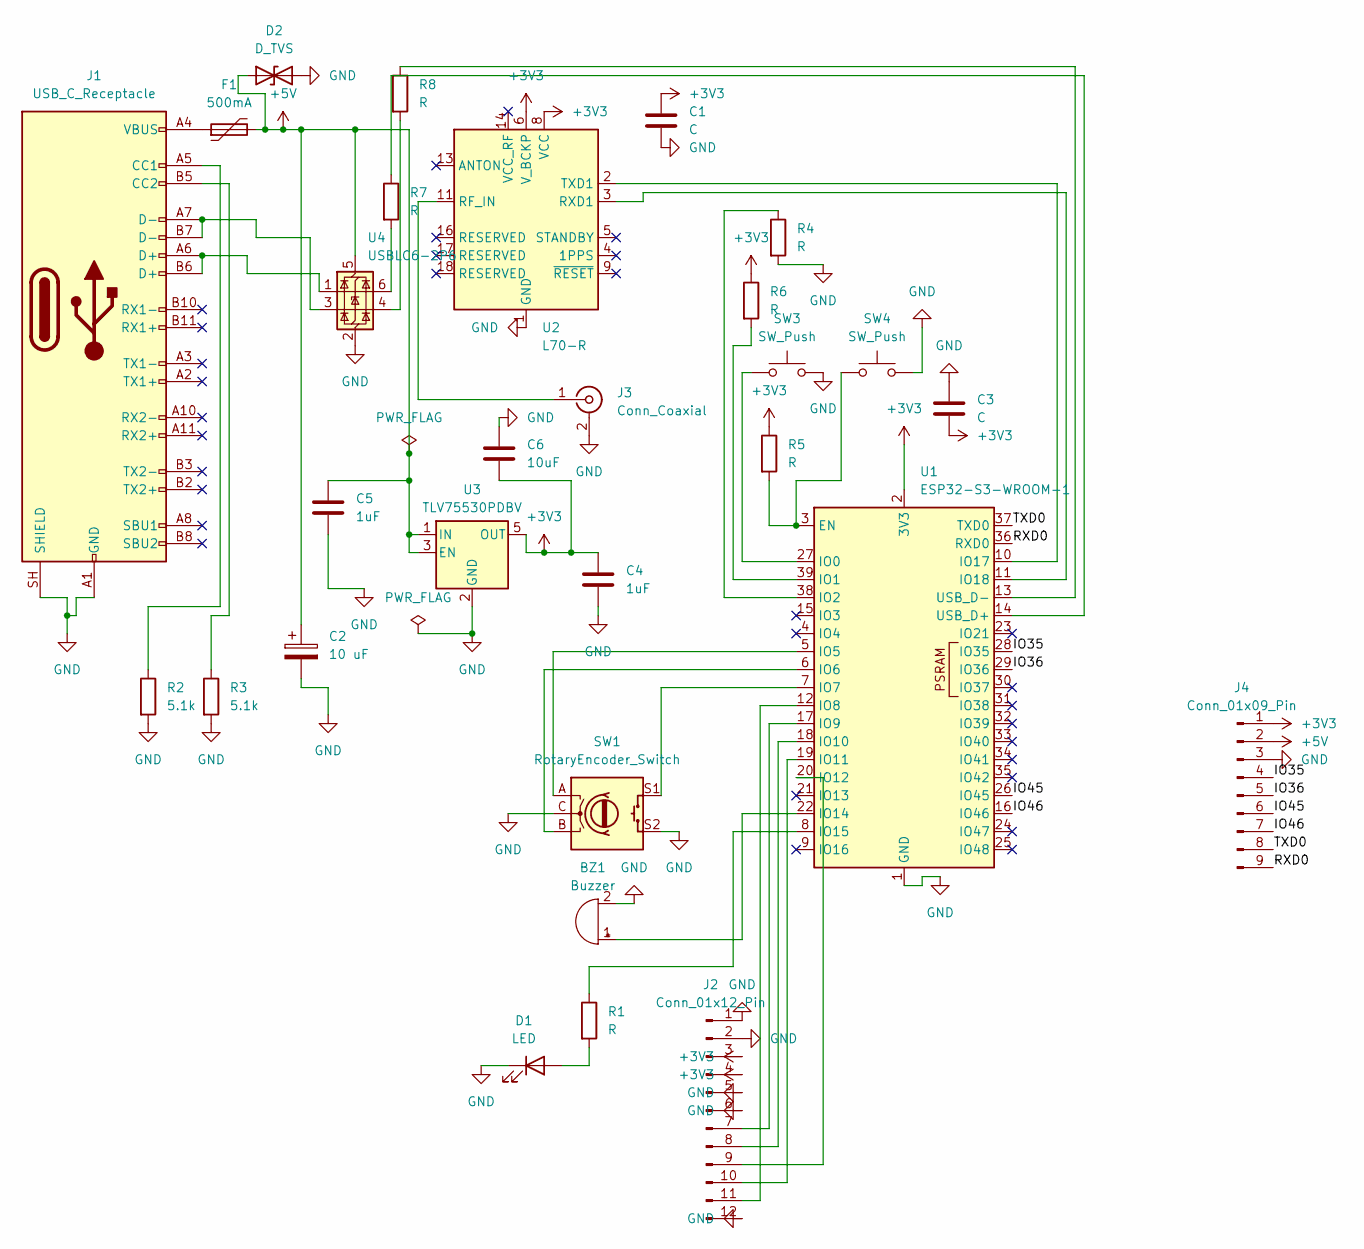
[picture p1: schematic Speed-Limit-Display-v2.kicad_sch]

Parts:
BZ1: Buzzer
C1, C3: C
C2: 10 uF
C4, C5: 1uF
C6: 10uF
D1: LED
D2: D_TVS
F1: 500mA
J1: USB_C_Receptacle
J2: Conn_01x12_Pin
J3: Conn_Coaxial
J4: Conn_01x09_Pin; PinHeader_1x09_P2.54mm_Vertical
R1, R4, R5, R6, R7, R8: R
R2, R3: 5.1k
SW1: RotaryEncoder_Switch
SW3, SW4: SW_Push
U1: ESP32-S3-WROOM-1
U2: L70-R; Quectel_L70-R
U3: TLV75530PDBV; SOT-23-5
U4: USBLC6-2P6; SOT-666

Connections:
+3V3: C1.1, C3.2, C4.1, C6.2, J2.3, J2.4, J4.1, R5.1, R6.1, U1.2 (3V3), U2.6 (V_BCKP), U2.8 (VCC), U3.5 (OUT)
+5V: C2.1, C5.1, D2.1 (A1), F1.2, J4.2, U3.1 (IN), U3.3 (EN), U4.5 (VBUS)
/IO35: J4.4, U1.28 (IO35)
/IO36: J4.5, U1.29 (IO36)
/IO45: J4.6, U1.26 (IO45)
/IO46: J4.7, U1.16 (IO46)
/RXD0: J4.9, U1.36 (RXD0)
/TXD0: J4.8, U1.37 (TXD0)
GND: BZ1.2 (-), C1.2, C2.2, C3.1, C4.2, C5.2, C6.1, D1.1 (K), D2.2 (A2), J1.A1 (GND), J1.A12 (GND), J1.B1 (GND), J1.B12 (GND), J1.SH (SHIELD), J2.1, J2.2, J2.5, J2.6, J2.12, J3.2 (Ext), J4.3, R2.2, R3.2, R4.2, SW1.C, SW1.S2, SW3.2, SW4.2, U1.1 (GND), U1.40 (GND), U1.41 (GND), U2.1 (GND), U2.10 (GND), U2.12 (GND), U3.2 (GND), U4.2 (GND)
unnamed: BZ1.1 (+), U1.22 (IO14)
unnamed: D1.2 (A), R1.2
unnamed: F1.1, J1.A4 (VBUS), J1.A9 (VBUS), J1.B4 (VBUS), J1.B9 (VBUS)
unnamed: J1.A5 (CC1), R2.1
unnamed: J1.B5 (CC2), R3.1
unnamed: J1.A6 (D+), J1.B6 (D+), U4.1 (I/O1)
unnamed: J1.A7 (D-), J1.B7 (D-), U4.3 (I/O2)
unnamed: J2.7, U1.17 (IO9)
unnamed: J2.8, U1.18 (IO10)
unnamed: J2.9, U1.20 (IO12)
unnamed: J2.10, U1.19 (IO11)
unnamed: J2.11, U1.12 (IO8)
unnamed: J3.1 (In), U2.11 (RF_IN)
unnamed: R7.2, U4.6 (I/O1)
unnamed: R8.2, U4.4 (I/O2)
unnamed: R5.2, SW4.1, U1.3 (EN)
unnamed: SW3.1, U1.27 (IO0)
unnamed: R6.2, U1.39 (IO1)
unnamed: R4.1, U1.38 (IO2)
unnamed: SW1.A, U1.5 (IO5)
unnamed: SW1.B, U1.6 (IO6)
unnamed: SW1.S1, U1.7 (IO7)
unnamed: R1.1, U1.8 (IO15)
unnamed: U1.10 (IO17), U2.2 (TXD1)
unnamed: U1.11 (IO18), U2.3 (RXD1)
unnamed: R7.1, U1.14 (USB_D+)
unnamed: R8.1, U1.13 (USB_D-)

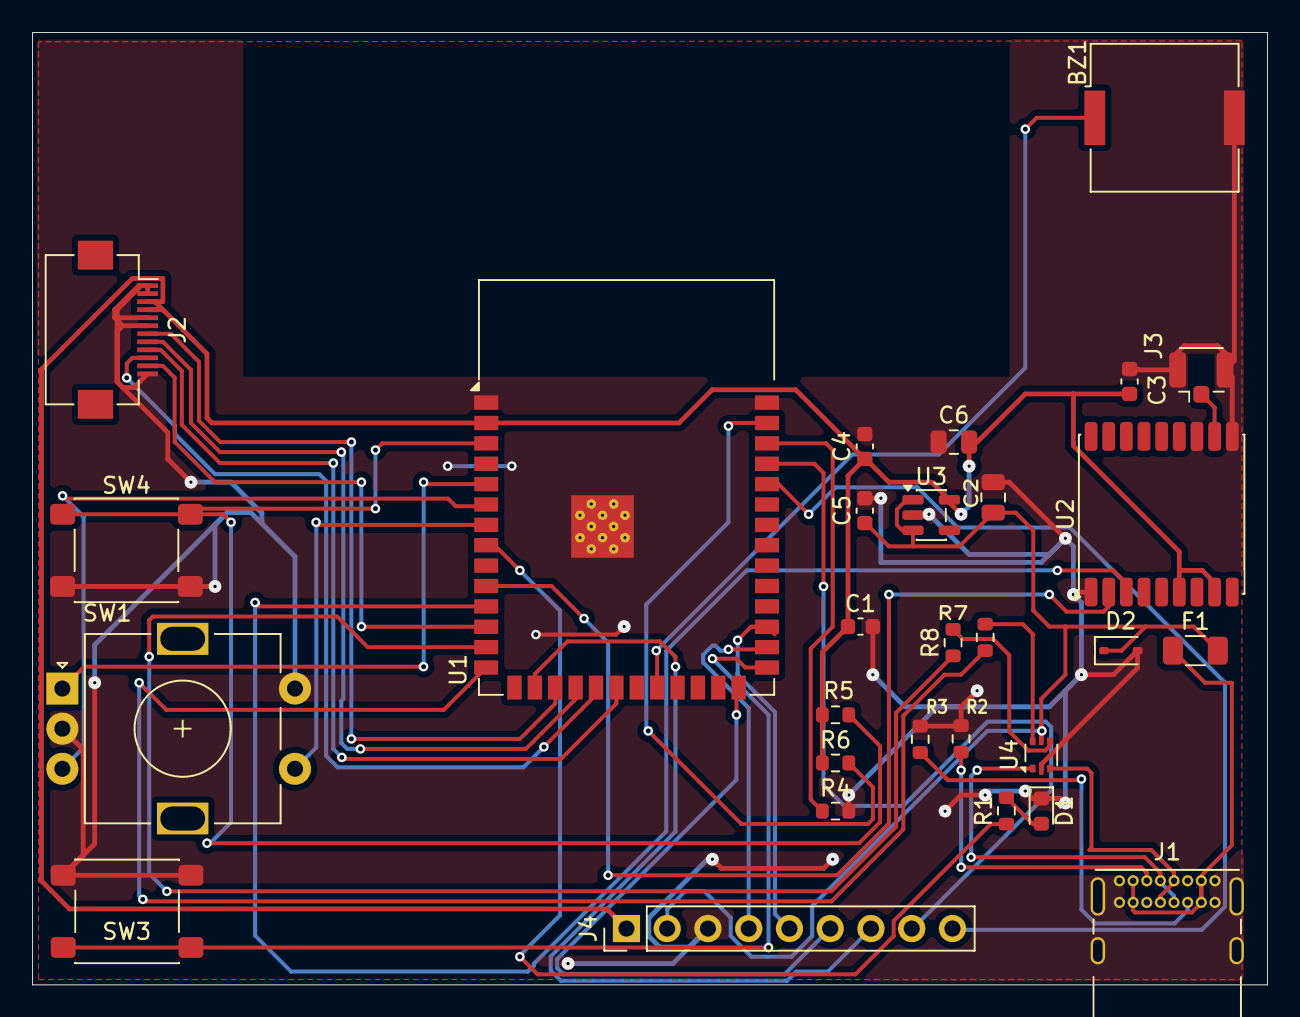
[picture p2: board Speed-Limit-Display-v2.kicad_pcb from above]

Board: 2 copper layers, 77.0 x 59.4 mm, 29 parts (0 on the bottom side), 36 nets.

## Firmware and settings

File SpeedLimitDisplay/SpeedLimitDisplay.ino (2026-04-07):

// =============================================
// SPEED LIMIT DISPLAY — Rev 4.1 (Phase 2)
// =============================================
// ESP32 Mini + GPS + SSD1351 OLED + TomTom API
//
// What this does:
//   - Reads your GPS position and heading
//   - Asks TomTom "what road am I on and what's the speed limit?"
//   - Shows the speed limit on the OLED display
//   - Changes color: GREEN (ok), YELLOW (close to limit), RED (over limit)
//
// Rev4 Phase 1 changes (vs Rev3):
//   - Uses TomTom "Snap to Roads" API instead of Reverse Geocode
//     → sends your heading and speed so TomTom picks the RIGHT road
//   - Buffers multiple GPS points for better road matching
//   - Speed limit smoothing — rejects wild jumps (side road false matches)
//   - GPS baud rate increased to 38400 (supports 10Hz without data loss)
//   - Non-blocking WiFi (GPS keeps working during WiFi reconnects)
//   - Low-speed dead zone (no false alerts when parked)
//   - Watchdog timer (auto-reboots if device freezes)
//   - Credentials in separate file (config_secrets.h)
//   - All tunable settings in config.h
//
// Rev4.1 Phase 2 changes:
//   - Dual-core background HTTP: API calls run on Core 0 while GPS/display
//     runs on Core 1. Display never freezes. Falls back to inline on single-core.
//   - API rate limit handling: detects HTTP 429, exponential backoff
//   - Daily API quota tracking with warnings at 80% usage
//   - WiFi exponential backoff: smarter reconnection (5s→10s→20s→40s→60s max)
//   - WiFi disconnect/reconnect event logging
//
// Hardware:
//   - ESP32 Mini (any variant: S2, S3, C3, or original)
//   - GPS module (UART, any NMEA-compatible like NEO-6M, NEO-7M, BN-220)
//   - SSD1351 128x128 SPI OLED display
//   - One pushbutton (between BTN_PIN and GND)
//
// Libraries needed (install via Arduino Library Manager):
//   - TinyGPSPlus (by Mikal Hart)
//   - ArduinoJson (by Benoit Blanchon, version 6.x)
//   - Adafruit GFX Library
//   - Adafruit SSD1351 Library
// =============================================

// IMPORTANT: This enum must be BEFORE includes so Arduino's
// auto-prototype generator doesn't break it.
// (Arduino IDE automatically creates function declarations at the top of your
//  code, but it can mess up if enums are defined after includes.)
enum BtnEvent : uint8_t { BTN_NONE, BTN_SHORT, BTN_LONG, BTN_VLONG };

// --- Standard Libraries ---
#include <WiFi.h>
#include <HTTPClient.h>
#include <ArduinoJson.h>
#include <Preferences.h>         // NVS = Non-Volatile Storage (survives reboots)
#include <esp_task_wdt.h>        // Watchdog timer

// --- Hardware Libraries ---
#include <TinyGPSPlus.h>
#include <SPI.h>
#include <Adafruit_GFX.h>
#include <Adafruit_SSD1351.h>

// --- Fonts ---
#include <Fonts/FreeSansBold24pt7b.h>
#include <Fonts/FreeSansBold9pt7b.h>

// --- Our Config Files ---
#include "config.h"              // Pin definitions, timing, thresholds
#include "config_secrets.h"      // WiFi password, API key (git-ignored)


// =============================================================
// SECTION 1: HARDWARE OBJECTS
// =============================================================
// These are the "objects" that represent your physical hardware.
// Think of them as software handles — you call methods on them
// to control the actual hardware.

// The OLED display. We tell it the screen size, which SPI bus, and which pins.
Adafruit_SSD1351 display(SCREEN_W, SCREEN_H, &SPI, OLED_CS, OLED_DC, OLED_RST);

// The GPS parser. It reads raw NMEA sentences (text from the GPS module)
// and turns them into useful data (latitude, longitude, speed, heading, etc.)
TinyGPSPlus gps;

// Hardware serial port #1 for GPS communication.
// ESP32 has multiple serial ports — Serial (USB) is #0, this is #1.
HardwareSerial GPSSerial(1);

// Non-volatile preferences storage (saves settings when power is off).
Preferences prefs;


// =============================================================
// SECTION 2: STATE VARIABLES
// =============================================================
// These track what's happening right now. They live in RAM and
// reset to their initial values every time the device reboots.

// --- GPS state ---
uint32_t bootMs       = 0;       // When the device started (millis timestamp)
uint32_t lastByteMs   = 0;       // Last time we received ANY data from GPS
uint32_t lastFixMs    = 0;       // Last time GPS had a valid position fix
uint32_t firstFixMs   = 0;       // First-ever valid fix (0 = never had one)
bool     haveFixEver  = false;   // Have we EVER gotten a GPS fix this session?

// --- Speed limit state ---
int      currentSpeedLimitMph = -1;   // Currently displayed speed limit (-1 = unknown)
uint32_t lastGoodLimitMs      = 0;    // When we last got a valid speed limit

// --- API call state ---
uint32_t lastApiMs     = 0;      // When we last called the TomTom API
uint32_t lastApiFailMs = 0;      // When the API last failed (for warning icon)
double   lastApiLat    = 0;      // GPS position of last API call
double   lastApiLon    = 0;
bool     haveApiPos    = false;  // Have we made at least one API call?

// --- User settings (saved to NVS) ---
int      brightIdx         = 0;       // Current brightness level index
float    brightnessScale   = 1.0f;    // Actual brightness multiplier (0.0-1.0)
int      yellowOverMph     = 3;       // Show yellow when this many mph over limit
int      redOverMph        = 4;       // Show red when this many mph over limit
uint32_t apiMinIntervalMs  = API_DEFAULT_INTERVAL_MS;
float    apiMinMoveM       = API_DEFAULT_MOVE_M;

// --- Display cache ---
// We only redraw the screen when something changes. These track what's
// currently shown so we can skip unnecessary redraws (which are slow on SPI).
String   lastMainText      = "";
uint16_t lastMainColor     = 0xFFFF;
int      lastShownSpeed    = -999;    // Last displayed current speed (for redraw check)
int      lastShownSats     = -999;
bool     lastGpsIconSolid  = false;
int      lastWifiBars      = -1;
bool     lastApiWarn       = false;

// --- Button state ---
bool     btnLastRead     = true;    // Last raw reading (HIGH = not pressed)
bool     btnStable       = true;    // Debounced stable state
uint32_t btnLastChangeMs = 0;       // When the raw reading last changed
uint32_t btnPressStartMs = 0;       // When current press started
bool     btnIsDown       = false;   // Is button currently held down?

// --- Menu state ---
bool menuActive = false;
int  menuIndex  = 0;
bool menuDirty  = true;             // Does the menu need to be redrawn?

// --- Overspeed state machine ---
// Uses hysteresis to prevent flickering between colors at the boundary.
// "Hysteresis" means it takes a slightly BIGGER change to switch states
// than it does to stay in the current state. Like a thermostat that turns
// on the heater at 68F but doesn't turn it off until 72F.
enum OverState : uint8_t { OK_GREEN, WARN_YELLOW, OVER_RED };
OverState overState = OK_GREEN;

// --- WiFi state (non-blocking with exponential backoff) ---
bool     wifiConnecting    = false;   // Are we in the middle of connecting?
uint32_t wifiConnectStart  = 0;       // When we started the current connection attempt
uint32_t wifiLastAttemptMs = 0;       // When we last tried to connect
uint32_t wifiRetryMs       = WIFI_RETRY_INITIAL_MS;  // Current backoff delay (grows on failures)
int      wifiFailCount     = 0;       // Consecutive failed attempts
bool     wifiWasConnected  = false;   // Were we connected last loop? (for disconnect logging)

// --- API rate limiting ---
// Tracks usage and implements exponential backoff when rate-limited.
int      apiCallsToday     = 0;       // Approximate API calls made today (resets on reboot)
uint32_t apiBackoffUntil   = 0;       // Don't make API calls until this millis() timestamp
uint32_t apiBackoffMs      = RATE_LIMIT_INITIAL_MS;  // Current backoff delay
bool     apiRateLimited    = false;   // Are we currently in a rate-limit backoff?
bool     apiQuotaWarned    = false;   // Have we already warned about approaching quota?

// --- GPS point buffer for Snap-to-Roads ---
// We store the last few GPS readings so we can send them all to TomTom.
// Multiple points help TomTom figure out which road you're actually on
// by looking at your trajectory (path of travel), not just one position.
struct GpsPoint {
  double   lat;
  double   lon;
  float    heading;     // Direction of travel in degrees (0=North, 90=East, etc.)
  float    speedKmh;    // Speed in km/h (TomTom expects metric)
  uint32_t timestamp;   // millis() when this point was captured
  bool     valid;       // Is this point filled in yet?
};

// --- Dual-core background HTTP ---
// On dual-core ESP32s, API calls run on Core 0 (background) while the main
// loop runs on Core 1. This prevents HTTP requests from freezing the display
// and losing GPS data.
//
// How it works:
//   1. Main loop sets requestNeeded = true and fills in the request lat/lon
//   2. Background task sees the flag, makes the HTTP call, stores the result
//   3. Main loop sees resultReady = true and reads the speed limit
//
// "volatile" tells the compiler: "another thread might change this variable
// at any time, so always read it from memory, don't cache it in a register."
struct HttpRequest {
  volatile bool    requestNeeded;   // Main loop → background: "please make an API call"
  volatile bool    resultReady;     // Background → main loop: "result is ready"
  volatile bool    taskRunning;     // Is the background task alive?
  double           lat;             // Request: GPS latitude
  double           lon;             // Request: GPS longitude
  GpsPoint         points[GPS_BUFFER_SIZE];  // Copy of GPS buffer for the request
  int              pointCount;      // How many valid points in the buffer
  volatile int     resultLimit;     // Response: speed limit (-1 = failed)
  volatile bool    resultFailed;    // Response: did the API call fail?
  volatile int     httpCode;        // Response: HTTP status code (for rate limit detection)
};

HttpRequest httpReq = { false, false, false, 0, 0, {}, 0, -1, false, 0 };
bool dualCoreAvailable = false;     // Set in setup() based on chip type

GpsPoint gpsBuffer[GPS_BUFFER_SIZE];
int      gpsBufferIndex = 0;   // Next slot to write into (circular buffer)
uint32_t lastBufferMs   = 0;   // When we last added a point to the buffer

// --- Speed limit smoothing ---
// Keeps a history of recent API results to detect and reject outliers.
// An "outlier" is a single reading that's wildly different from recent values —
// usually caused by GPS matching a nearby road by mistake.
int  limitHistory[LIMIT_HISTORY_SIZE];
int  limitHistoryCount = 0;       // How many values are in the history
int  pendingLimit      = -1;      // A "suspicious" new limit waiting for confirmation
int  pendingConfirms   = 0;       // How many times we've seen the pending limit


// =============================================================
// SECTION 3: COLORS (RGB565)
// =============================================================
// The SSD1351 display uses "RGB565" color format:
//   - 5 bits for Red (0-31)
//   - 6 bits for Green (0-63) — human eyes are more sensitive to green
//   - 5 bits for Blue (0-31)
// These are packed into a single 16-bit number.

static inline uint16_t C_BLACK()  { return 0x0000; }
static inline uint16_t C_WHITE()  { return 0xFFFF; }
static inline uint16_t C_GRAY()   { return 0x8410; }
static inline uint16_t C_GREEN()  { return 0x07E0; }
static inline uint16_t C_YELLOW() { return 0xFFE0; }
static inline uint16_t C_RED()    { return 0xF800; }

// Apply software brightness dimming to a color.
// We multiply each color channel by the brightness scale factor.
uint16_t scaleColor(uint16_t color) {
  if (color == C_BLACK()) return color;   // Black stays black regardless

  // Extract the individual R, G, B channels from the packed 16-bit value
  uint8_t r = (color >> 11) & 0x1F;   // Top 5 bits
  uint8_t g = (color >> 5)  & 0x3F;   // Middle 6 bits
  uint8_t b =  color        & 0x1F;   // Bottom 5 bits

  // Scale each channel by brightness
  r = (uint8_t)(r * brightnessScale);
  g = (uint8_t)(g * brightnessScale);
  b = (uint8_t)(b * brightnessScale);

  // Clamp to max values (shouldn't exceed, but safety first)
  if (r > 31) r = 31;
  if (g > 63) g = 63;
  if (b > 31) b = 31;

  // Pack back into RGB565
  return (r << 11) | (g << 5) | b;
}


// =============================================================
// SECTION 4: SERIAL COMMANDS
// =============================================================
// You can type commands over USB Serial (the Arduino Serial Monitor).
// This is useful for debugging — type 'r' to reboot, 'd' for debug info.

void checkSerialCommands() {
  while (Serial.available()) {
    char c = (char)Serial.read();
    if (c == 'r' || c == 'R') {
      Serial.println("[CMD] Rebooting...");
      delay(100);
      ESP.restart();
    }
    else if (c == 'd' || c == 'D') {
      // Print current state for debugging
      Serial.println("=== DEBUG INFO ===");
      Serial.printf("  GPS fix: %s | Sats: %d\n",
        gps.location.isValid() ? "YES" : "NO",
        gps.satellites.isValid() ? gps.satellites.value() : 0);
      Serial.printf("  Lat: %.6f  Lon: %.6f\n",
        gps.location.isValid() ? gps.location.lat() : 0.0,
        gps.location.isValid() ? gps.location.lng() : 0.0);
      Serial.printf("  Heading: %.1f°  Speed: %.1f mph\n",
        gps.course.isValid() ? gps.course.deg() : 0.0,
        gps.speed.isValid() ? gps.speed.mph() : 0.0);
      Serial.printf("  WiFi: %s (RSSI: %d)\n",
        WiFi.status() == WL_CONNECTED ? "Connected" : "Disconnected",
        WiFi.status() == WL_CONNECTED ? WiFi.RSSI() : 0);
      Serial.printf("  Speed limit: %d mph\n", currentSpeedLimitMph);
      Serial.printf("  API calls since boot: interval=%lums, move=%.0fm\n",
        apiMinIntervalMs, apiMinMoveM);
      Serial.printf("  Brightness: level %d/%d (%.0f%%)\n",
        brightIdx + 1, BRIGHT_LEVEL_COUNT, brightnessScale * 100);
      Serial.printf("  Buffer points: %d/%d\n",
        min(limitHistoryCount, LIMIT_HISTORY_SIZE), LIMIT_HISTORY_SIZE);
      Serial.printf("  Dual-core: %s\n", dualCoreAvailable ? "YES (HTTP on Core 0)" : "NO (inline HTTP)");
      Serial.printf("  API calls today: ~%d / %d\n", apiCallsToday, API_DAILY_LIMIT);
      Serial.printf("  Rate limited: %s", apiRateLimited ? "YES" : "no");
      if (apiRateLimited) Serial.printf(" (backoff: %lu ms)", apiBackoffMs);
      Serial.println();
      Serial.printf("  WiFi fails: %d (retry delay: %lu ms)\n", wifiFailCount, wifiRetryMs);
      Serial.println("==================");
    }
  }
}


// =============================================================
// SECTION 5: PREFERENCES (Persistent Settings)
// =============================================================
// NVS (Non-Volatile Storage) is flash memory on the ESP32 that
// survives reboots and power cycles. We use it to remember your
// brightness level, alert thresholds, etc.

void saveSettings() {
  prefs.putUChar("bri", (uint8_t)brightIdx);
  prefs.putUChar("yov", (uint8_t)yellowOverMph);
  prefs.putUChar("rov", (uint8_t)redOverMph);
  prefs.putUInt("apiI", apiMinIntervalMs);
  prefs.putUInt("apiM", (uint32_t)lround(apiMinMoveM));
}
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
void loop() {
  // Pet the watchdog — "I'm still alive!"
  // If we don't do this within WATCHDOG_TIMEOUT_SEC seconds, the ESP32 reboots.
  esp_task_wdt_reset();

  // Check for serial commands (type 'r' to reboot, 'd' for debug)
  checkSerialCommands();

  // --- Button handling ---
  BtnEvent ev = pollButtonEvent();
  if (!menuActive) {
    if (ev == BTN_SHORT) nextBrightnessLevel();
    else if (ev == BTN_LONG) enterMenu();
  } else {
    if (ev == BTN_SHORT) menuNext();
    else if (ev == BTN_LONG) menuChangeCurrent();
    else if (ev == BTN_VLONG) exitMenu();
  }

  // --- Read ALL available GPS data ---
  // We read everything available right now. The GPS module sends data
  // constantly (10 times per second at 10Hz), so we need to keep up.
  while (GPSSerial.available()) {
    gps.encode(GPSSerial.read());
    lastByteMs = millis();
  }

  // --- GPS fix tracking ---
  bool nmeaFlowing = (millis() - lastByteMs) < 1500;
  bool fixValid = gps.location.isValid() && gps.location.age() < 2000;

  if (fixValid) {
    haveFixEver = true;
    lastFixMs = millis();
    if (firstFixMs == 0) firstFixMs = millis();

    // Buffer GPS point every 500ms (2 points per second)
    // More frequent than API calls, so we build up a trajectory
    if ((millis() - lastBufferMs) >= 500) {
      bufferGpsPoint();
    }
  }

  bool inGrace       = (millis() - bootMs) < GPS_GRACE_MS;
  bool recentlyHadFix = (millis() - lastFixMs) < GPS_LOST_HOLD_MS;
  bool acquiring      = nmeaFlowing && !fixValid && (inGrace || !haveFixEver);
  bool blinkOn        = ((millis() / GPS_BLINK_MS) % 2) == 0;

  int sats = gps.satellites.isValid() ? gps.satellites.value() : 0;

  // --- WiFi management (non-blocking) ---
  bool wifiReady = wifiManage();
  int wBars = wifiReady ? wifiBars() : 0;

  // --- API warning icon ---
  // Shows "!" in the status bar when something is wrong with API calls.
  bool recentFail = (millis() - lastApiFailMs) < API_WARN_WINDOW_MS;
  bool noLimitTooLong = (fixValid && currentSpeedLimitMph <= 0 &&
                         firstFixMs != 0 && (millis() - firstFixMs) > API_NO_LIMIT_WARN_MS);
  bool apiWarn = recentFail || noLimitTooLong || apiRateLimited;

  // --- Draw status bar ---
  drawTopStatusBar(fixValid, acquiring ? blinkOn : false, sats, wBars, apiWarn);

  // --- Menu mode ---
  if (menuActive) {
    drawMenuScreen();
    delay(25);
    return;   // Skip everything else while in the menu
  }

  // --- No GPS data flowing? ---
  if (!nmeaFlowing) { delay(25); return; }
  if (!fixValid && !haveFixEver) { drawMain("--", C_GRAY()); delay(25); return; }
  if (!fixValid && !recentlyHadFix) { drawMain("--", C_GRAY()); delay(25); return; }

  // --- Get current position ---
  double lat = gps.location.isValid() ? gps.location.lat() : lastApiLat;
  double lon = gps.location.isValid() ? gps.location.lng() : lastApiLon;

  // --- Get current speed (with dead zone) ---
  int speedMph = 0;
  if (gps.speed.isValid() && gps.speed.age() < 2000) {
    speedMph = (int)lround(gps.speed.mph());

    // Dead zone: GPS is noisy at low speeds. If the GPS says 1-2 mph
    // when you're actually parked, we treat it as 0 to prevent false alerts.
    if (speedMph < SPEED_DEAD_ZONE_MPH) speedMph = 0;
  }

  // --- Check for background HTTP results (dual-core mode) ---
  // If the background task finished an API call, pick up the result.
  if (dualCoreAvailable && httpReq.resultReady) {
    httpReq.resultReady = false;   // Acknowledge the result

    if (httpReq.httpCode == 429) {
      // Rate limited! Start exponential backoff.
      handleRateLimit();
      lastApiFailMs = millis();
    } else if (httpReq.resultLimit > 0) {
      // Got a valid speed limit — apply smoothing
      int smoothed = smoothSpeedLimit(httpReq.resultLimit);
      currentSpeedLimitMph = smoothed;
      lastGoodLimitMs = millis();
      lastApiLat = httpReq.lat;
      lastApiLon = httpReq.lon;
      haveApiPos = true;
      resetRateLimitBackoff();   // Successful call, reset backoff
    } else {
      lastApiFailMs = millis();
    }

    lastApiMs = millis();
  }

  // --- Should we request an API call? ---
  bool timeOk = (millis() - lastApiMs) >= apiMinIntervalMs;
  bool moveOk = true;
  if (haveApiPos) {
    moveOk = distanceMeters(lat, lon, lastApiLat, lastApiLon) >= apiMinMoveM;
  }
  bool rateLimitOk = !apiRateLimited || (millis() >= apiBackoffUntil);

  if (timeOk && moveOk && wifiReady && rateLimitOk) {
    if (dualCoreAvailable) {
      // --- DUAL-CORE: hand off to background task (non-blocking!) ---
      // We only start a new request if the background task isn't already busy.
      if (!httpReq.requestNeeded) {
        prepareHttpRequest(lat, lon);
        lastApiMs = millis();   // Mark that we've initiated a call
      }
    } else {
      // --- SINGLE-CORE: make the API call inline (blocks briefly) ---
      int httpCode = 0;
      int rawLimit = fetchSpeedLimit(lat, lon, &httpCode);

      if (httpCode == 429) {
        handleRateLimit();
        lastApiFailMs = millis();
      } else if (rawLimit > 0) {
        int smoothed = smoothSpeedLimit(rawLimit);
        currentSpeedLimitMph = smoothed;
        lastGoodLimitMs = millis();
        lastApiLat = lat;
        lastApiLon = lon;
        haveApiPos = true;
        resetRateLimitBackoff();
      } else {
        lastApiFailMs = millis();
      }

      lastApiMs = millis();
    }
  }

  // --- Is the speed limit still fresh enough to display? ---
  bool haveRecentLimit = (currentSpeedLimitMph > 0) &&
                         ((millis() - lastGoodLimitMs) < LIMIT_HOLD_MS);

  if (!haveRecentLimit) {
    drawCurrentSpeed(speedMph);   // Still show your speed even without a limit
    drawMain("--", C_GRAY());
    delay(25);
    return;
  }

  // --- Update overspeed state and display ---
  overState = computeOverState(speedMph, currentSpeedLimitMph);
  drawCurrentSpeed(speedMph);
  drawMain(String(currentSpeedLimitMph), colorForOverState(overState));

  delay(25);
}

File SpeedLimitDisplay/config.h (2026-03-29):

// =============================================
// CONFIGURATION — All tunable settings in one place
// =============================================
// This file is safe to push to GitHub (no secrets here).
// Secrets (WiFi password, API key) live in config_secrets.h
//
// If you want to change pin wiring, timing, thresholds, or
// display settings, do it here — not in the main .ino file.

#ifndef CONFIG_H
#define CONFIG_H

// =====================
// HARDWARE PINS
// =====================

// --- OLED Display (SPI) ---
// These are the wires connecting your ESP32 to the OLED screen.
// SPI = "Serial Peripheral Interface" — a fast way to talk to displays.
#define SCREEN_W    128       // Screen width in pixels
#define SCREEN_H    128       // Screen height in pixels
#define OLED_CS     7         // Chip Select — tells the display "I'm talking to you"
#define OLED_DC     2         // Data/Command — tells display if we're sending a command or pixel data
#define OLED_RST    3         // Reset — restarts the display on boot
#define SPI_MOSI    4         // Master Out Slave In — the data wire (ESP32 sends pixels here)
#define SPI_SCLK    6         // Serial Clock — timing signal for SPI

// --- GPS Module (UART / Serial) ---
// UART = "Universal Asynchronous Receiver Transmitter" — how the GPS talks to the ESP32.
// GPS TX wire -> ESP32 RX pin (GPS sends data TO the ESP32)
// GPS RX wire -> ESP32 TX pin (ESP32 sends commands TO the GPS)
static const int GPS_RX_PIN = 20;    // ESP32 receives GPS data on this pin
static const int GPS_TX_PIN = 21;    // ESP32 sends commands to GPS on this pin

// --- Button ---
// One button does everything: short press = brightness, long press = menu.
// Wiring: one leg to BTN_PIN, other leg to GND. We use INPUT_PULLUP
// (the ESP32 has a built-in resistor that keeps the pin HIGH when not pressed).
static const int BTN_PIN = 10;

// =====================
// GPS SETTINGS
// =====================

// Baud rate = how fast data flows over the serial wire (bits per second).
// 9600 is the GPS default but too slow for 5Hz updates with multiple messages.
// 38400 gives plenty of bandwidth. The code sends a UBX command to the GPS
// module to change its baud rate, then switches our serial port to match.
static const uint32_t GPS_TARGET_BAUD = 38400;

// GPS update rate.
// The GT-U7 (u-blox NEO-6M) can reliably do 5Hz (5 position fixes per second).
// Some clones claim 10Hz but it's often unstable. 5Hz is 5x better than the
// 1Hz default and plenty for driving. The code uses UBX-CFG-RATE to set this.
// NOTE: u-blox modules use UBX binary protocol. The PMTK text commands used
// by MediaTek GPS chips (BN-220, etc.) will NOT work on the GT-U7.
static const int GPS_UPDATE_RATE_HZ = 5;

// How many GPS points to buffer for the Snap-to-Roads API.
// More points = better road matching, but uses more memory and bigger API request.
// 5 is a sweet spot: enough history for TomTom to figure out your trajectory.
static const int GPS_BUFFER_SIZE = 5;

// Grace period after boot — don't show errors while GPS is still getting its first fix.
// Cold start can take 30-60 seconds, so we wait 60s before complaining.
static const uint32_t GPS_GRACE_MS = 60000;

// After losing GPS fix, keep showing the last known data for this long.
// Covers brief signal drops (tunnels, overpasses).
static const uint32_t GPS_LOST_HOLD_MS = 15000;

// GPS icon blink rate when searching for satellites (milliseconds per blink).
static const uint32_t GPS_BLINK_MS = 500;

// Speeds below this are treated as "stopped" (GPS is noisy at low speeds).
// Without this, GPS might say 2mph when you're parked, which could
// trigger false overspeed warnings in a parking lot.
static const int SPEED_DEAD_ZONE_MPH = 3;

// =====================
// API SETTINGS
// =====================

// Minimum time between TomTom API calls (milliseconds).
// Lower = more frequent updates, but burns through your free 2,500/day quota faster.
// At 4 seconds: ~900 calls/hour = ~2.7 hours of driving per day on free tier.
// At 8 seconds: ~450 calls/hour = ~5.5 hours/day.
static const uint32_t API_DEFAULT_INTERVAL_MS = 5000;

// Minimum distance you must move before making another API call (meters).
// Prevents wasting API calls when stopped at a red light.
// At 60mph you travel ~27m per second, so 20m means roughly 1 call per second
// at highway speeds (but the time interval above is the real limiter).
static const float API_DEFAULT_MOVE_M = 20.0f;

// How long to keep showing a speed limit after the last successful API response.
// If we can't reach the API for this long, we show "--" instead of stale data.
static const uint32_t LIMIT_HOLD_MS = 180000;    // 3 minutes

// Show a warning icon if the API has been failing for this long.
static const uint32_t API_WARN_WINDOW_MS = 30000; // 30 seconds

// Show a warning if we have GPS but no speed limit data after this long.
static const uint32_t API_NO_LIMIT_WARN_MS = 20000; // 20 seconds
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

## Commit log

2026-03-29 feat: add Rev4 sketch with Snap-to-Roads API and accuracy fixes
    Complete rewrite from Rev3 with major improvements:
    - TomTom Snap-to-Roads API (sends heading + speed for correct road matching)
    - GPS point buffer (5-point trajectory for better map matching)
    - Speed limit smoothing (rejects outlier readings, requires confirmation)
    - GPS baud rate increased to 38400 (supports 10Hz without data loss)
    - Non-blocking WiFi (GPS keeps updating during reconnects)
    - Low-speed dead zone (no false alerts when parked)
    - Watchdog timer (auto-reboot on freeze)
    - Credentials separated into config_secrets.h (git-ignored)
    - All tunable settings in config.h
    - Proper Arduino sketch folder structure (SpeedLimitD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
    [SpeedLimitDisplay.ino, config.h]
2026-03-29 feat: Phase 2 — dual-core HTTP, rate limiting, WiFi backoff
    Dual-core background HTTP (ESP32 original/S3):
    - API calls run on Core 0 via FreeRTOS task
    - GPS/display/buttons run on Core 1 uninterrupted
    - Auto-detects chip cores at boot, falls back to inline on single-core
    - Shared struct with volatile flags for cross-core communication
    API rate limit handling:
    - Detects HTTP 429 responses from TomTom
    - Exponential backoff: 10s → 20s → 40s → 80s → 120s max
    - Tracks approximate daily API calls (resets on reboot)
    - Warns at 80% of 2,500 daily free tier limit
    - Status bar shows "!" icon during rate-limit backoff
    WiFi exponential backoff:
    - Failed connection attempts increase retry del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
    [SpeedLimitDisplay.ino, config.h]
2026-03-29 docs: add README and contributing guide
    README covers hardware, wiring, setup, features, and project structure.
    CONTRIBUTING explains the branch workflow (main/dev/feature branches),
    how to make changes, and rules for collaborators.
2026-03-29 docs: add full product roadmap (15 phases, prototype to sales)
    Covers: field testing, display/UI upgrades, audio alerts, WiFi setup
    portal, OTA updates, custom PCB design, enclosure, sponsor video,
    product listing (Etsy + website), and post-launch planning.
    Includes BOM cost estimate and timeline.
2026-03-29 docs: add hardware pinout maps, PCB design spec, and updated roadmap
    Hardware docs:
    - ESP32-C3 prototype pinout with full wiring diagrams
    - GT-U7 GPS module specs and u-blox compatibility notes
    - Product PCB design: ESP32-S3 + GPS + touchscreen TFT
    - Complete BOM with pricing (~$17/board)
    - PCB layout guidelines (GPS antenna keep-out, power routing, SPI)
    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
2026-03-29 fix: replace PMTK commands with u-blox UBX protocol for GT-U7 GPS
    The GT-U7 GPS module uses a u-blox NEO-6M compatible chip which speaks
    UBX binary protocol, NOT MediaTek PMTK text commands. The previous PMTK
    commands were being silently ignored, leaving the GPS at 1Hz default
    instead of the intended higher update rate.
    Changes:
    - New ubxSend() function: handles UBX framing, Fletcher checksum, transmission
    - gpsSetUpdateRate(): UBX-CFG-RATE, sets 5Hz (NEO-6M reliable max, up from 1Hz)
    - gpsSetAutomotiveMode(): UBX-CFG-NAV5, dynModel=4 (automotive filtering)
    - gpsConfigureMessages(): UBX-CFG-MSG, enables only RMC+GGA, disables GLL/GSA/GSV/VTG
    - gpsSetBaudRate(): UBX-CFG-PRT, changes GPS UART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
    [SpeedLimitDisplay.ino, config.h]
2026-03-30 fix: resolve compile errors on ESP32-C3 + add multi-WiFi support
    Compile fixes:
    - Move GpsPoint struct definition before HttpRequest (was referenced
    before being defined, causing 'does not name a type' error)
    - Update esp_task_wdt_init() to use config struct API (ESP32-C3's
    newer ESP-IDF requires esp_task_wdt_config_t, not two-arg version)
    Multi-WiFi:
    - config_secrets.h now supports multiple WiFi networks as an array
    - Device auto-scans and connects to whichever known network is found
    - Seamlessly switches between home WiFi and phone hotspot
    - Falls back to first network in list if scan finds nothing
    - Updated config_secrets_example.h to show new format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
    [SpeedLimitDisplay.ino]
2026-03-31 feat: show current driving speed on display alongside speed limit
    Display now shows two numbers:
    - Current speed (smaller, top area, white) — updates frequently
    - Speed limit (big, center, color-coded) — updates on API response
    Layout: status bar → "45 mph" → big "65" → "LIMIT"
    Current speed updates independently from speed limit to avoid
    flickering the whole screen when only speed changes. Each section
    only redraws when its value actually changes.
    Shows current speed even when no speed limit is available ("-- mph"
    when stopped, actual speed when moving without limit data).
    [SpeedLimitDisplay.ino]
2026-04-05 feat: add KiCad schematic, product plan, and DRC checklist
    Add rebuilt KiCad v2 schematic (ESP32-S3, L70-R GPS, TLV75530 LDO,
    USB-C with ESD protection), product plan with phase tracking, and
    DRC fixes checklist. Update .gitignore for KiCad artifacts.
    [Speed-Limit-Display-v2-Backup.kicad_sch, Speed-Limit-Display-v2.csv, Speed-Limit-Display-v2.kicad_pcb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]
2026-04-05 feat: complete PCB layout with full routing, GND pour, and DRC passing
    PCB layout fully routed in KiCad with all traces connected, GND copper
    pour on both layers, stitching vias, and custom DRC rules for USB-C
    connector clearance. Updated PCB design docs and DRC checklist to
    reflect current state. Board is ready for Gerber generation.
    [Speed-Limit-Display-v2-Backup.kicad_sch, Speed-Limit-Display-v2.kicad_pcb, Speed-Limit-Display-v2.kicad_sch]
2026-04-06 feat: add J4 breakout header, Gerber/ordering docs, final DRC clean
    Added 9-pin breakout header (J4) exposing IO35, IO36, IO45, IO46,
    TXD0, RXD0, +3V3, +5V, GND for future sensor expansion. Updated
    PCB design docs with step-by-step Gerber generation instructions,
    PCBWay/JLCPCB ordering guide, component sourcing, and assembly notes.
    Final DRC: 0 errors, 2 cosmetic silkscreen warnings only.
    [Speed-Limit-Display-v2.kicad_pcb, Speed-Limit-Display-v2.kicad_sch]
2026-04-07 feat: add Gerber files, update README and product plan
    Added zipped Gerber + drill files ready for PCBWay/JLCPCB upload.
    Updated README with custom PCB section and full project structure.
    Updated product plan: Phase 3 PCB Design marked as nearly complete
    (5/6 tasks done, only board ordering remains).
    [Speed-Limit-Display-v2.kicad_pcb]
